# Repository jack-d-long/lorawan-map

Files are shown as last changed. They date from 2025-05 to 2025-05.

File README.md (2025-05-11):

# LoRaWAN Tracker
*Modified Spring 2025 by Jack Long, Charlie Hart, Aleira Sanchez, Chloe Teig for MAE 4220: IoT, Cornell University*

*Originally by Alex Coy, ECE 4950 TA for Spring 2021*

A one‑stop repository for everything you need to build, deploy, and visualize data from our GPS LoRaWAN tracker:

- **Map App** (`map‑app/`)  
  A lightweight web application for ingesting the raw `.txt` logs off the tracker’s onboard SD card and rendering an interactive, real‑time map of your device’s journey.

- **Tracker Hardware** (`tracker‑hardware/`)  
  - **Shell** (`tracker‑hardware/shell_CAD/`)  
    Fully parametric OpenSCAD/STEP files and detailed drawings for 3D‑printing or CNC fabrication of the tracker enclosure.  
  - **Firmware** (`tracker‑hardware/firmware/`)  
    PlatformIO‑compatible C/C++ code for the microcontroller: SD‑card logger, GNSS reader, LoRaWAN uplink, and low‑power sleep modes with GUI.
  - **Purple Board** (`tracker‑hardware/firmware/`)
    KiCAD-compatible files for manufacture and assembly of the EERL 'Purple Board' PCB by Alex Coy, current as of May 2025. 
---

## Repository Structure

```plaintext
lorawan-map/
├── map-app/                   # Web application
│   ├── connectivity_app.py    # Streamlit entrypoint
│   ├── requirements.txt       # Python dependencies
│   ├── templates/             # HTML templates
│
├── tracker-hardware/          
│   ├── shell_CAD/                   # OpenSCAD & STEP enclosure files
│   ├── purple_board/                # EERL purple board docs
│   └── firmware/              
│       ├── feather_sd_sam-m8q-/     # C/C++ source with all proprietary headers
│
├── .gitignore                 
└── README.md                  # ← you are here

```

## The LoRaWAN Tracker 

###  Features

- **Scan and Record LoRaWAN connectivity** Either store data onboard the SD or pull from The Things Network for custom database integration
- **Battery‑aware operation**: real‑time voltage monitoring and on‑screen battery bar  
- **Dual scan modes** (“Drive” vs “Walk”) with adaptive transmit intervals (15 s vs 60 s)  
- **Non‑blocking UI controls**: five‑button D‑pad menu navigation with hardware‑debounced inputs  
- **Persistent storage**: 32 kB FRAM for network session state (optional) + SD card for full JSON logging  
- **Plug‑and‑play web front‑end**: drag‑and‑drop `.txt` logs to visualize GPS tracks, timestamps and sensor graphs  

---

###  Hardware Requirements

- **Microcontroller**: Adafruit Feather M0 LoRa ([RFM95, 915 MHz](https://www.adafruit.com/product/3178))  
- **"Purple Board"**: EERL PCB (source included)
- **Display**: [SH1106 128×64 I²C OLED](https://www.aliexpress.us/item/3256806846801359.html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)
- **GPS**: u‑blox SAM‑M8Q module ([Sparkfun breakout](https://www.sparkfun.com/sparkfun-gps-breakout-chip-antenna-sam-m8q-qwiic.html))  
- **Storage**: [MicroSD card breakout](https://www.amazon.com/UMLIFE-Interface-Conversion-Compatible-Raspberry/dp/B0989SM146) with Micro SD (>8GB) + MCCI Catena cFram32k FRAM (optional)
- **Controls**: [PCA9554 I²C D‑Pad](https://www.sparkfun.com/sparkfun-qwiic-directional-pad.html) + [12mm latching pushbutton](https://www.amazon.com/Gebildet-Latcting-Lockable-Trumpet-Doorbell/dp/B07YDCJFZJ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)
- **Power**: 3.7 V 1S/3C LiPo battery (800-1000 mAh)   
- **Enclosure**: 3D‑printed shell (source included)  

---

### Software Requirements

- **Arduino IDE**   
- Libraries:  
  - `Arduino_LoRaWAN_ttn` + `lmic`  
  - `Adafruit GFX` & `Adafruit SH110X`  
  - `SparkFun u‑blox GNSS` & `TinyGPS`  
  - `SparkFun I2C Expander`  
  - `MCCI Catena FrAM`  
- **Node.js** (v14+) & **npm** for the web app  
- Web dependencies: `express`, `react`, `leaflet`, `chart.js`

---

## Usage

**1. Clone the repo**
```
git clone https://github.com/jack-d-long/lorawan-map.git
cd lorawan-map
```

**2. Build the tracker**
- Purchase components, print shell, assemble.
  - Printed with PLA at 0.2 mm layer height, tree supports
- Flash firmware with Arduino IDE

**3. Use the tracker**
- Collect data on LoRaWAN connectivity in your local area

**4. Set up the map app**
- Install dependencies

```
pip install --upgrade pip
pip install \
  streamlit \
  pandas \
  pydeck \
  jsonschema  # optional: validate JSON if you extend
```

**5. Read your stored data card with the map app**
- Read your tracker's SD storage with your computer
- Run the app

```
streamlit run connectivity_app.py
```
- Drag and drop the `.txt` file from the SD into the app
- Read your map!

**6. Read your data on the cloud via TTN**

- Set up TTN by following Labs 3, 4, 5, and 6 of [this tutorial](https://pages.github.coecis.cornell.edu/LPWAN-Training/training-labs/lab3), or equivalent
- Pipe your data via MQTT to the database of your choice for live retrieval

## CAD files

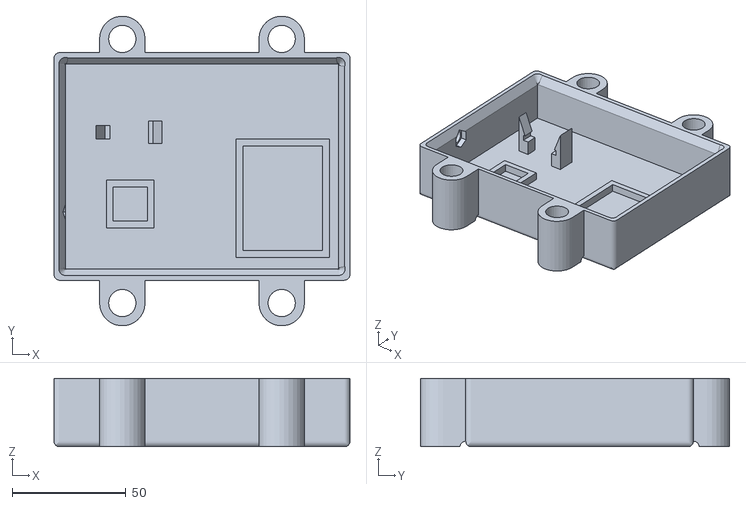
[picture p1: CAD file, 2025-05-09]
tracker-hardware/shell_CAD/car_mount/top_encl_sam_m8q.stl
130.0 x 135.9 x 30.0

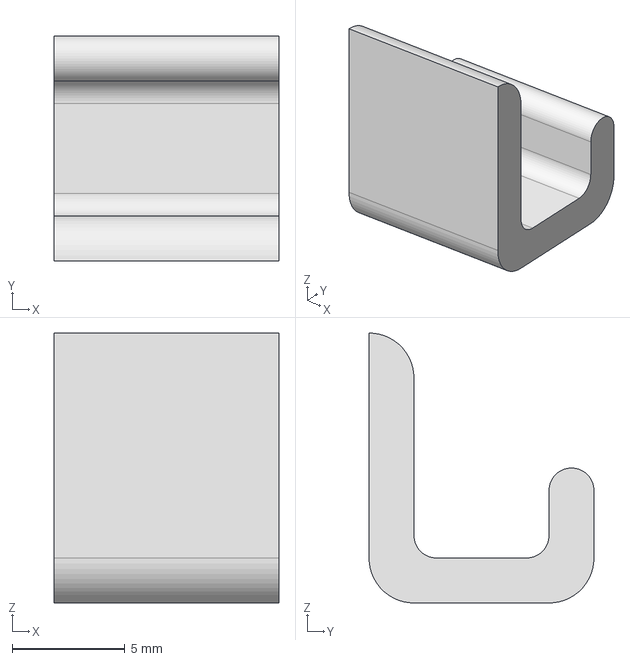
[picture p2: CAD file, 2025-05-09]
tracker-hardware/shell_CAD/handheld/V3/step/Car Window Mount.stp
10.0 x 10.0 x 12.0 mm

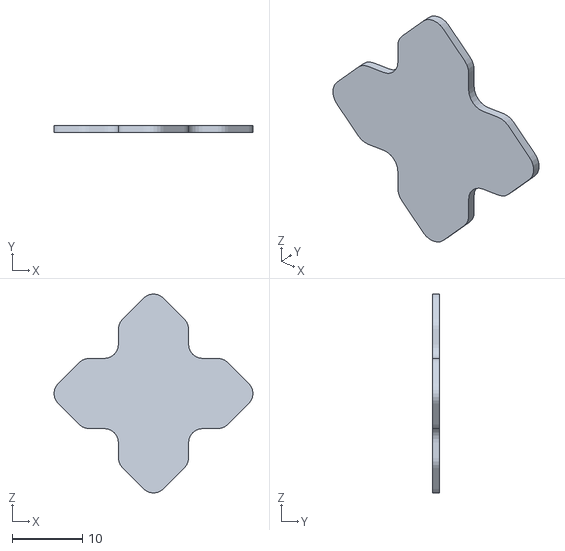
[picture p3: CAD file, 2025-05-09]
tracker-hardware/shell_CAD/handheld/V3/stl/D-pad cover new.stl
28.3 x 1.00 x 28.3

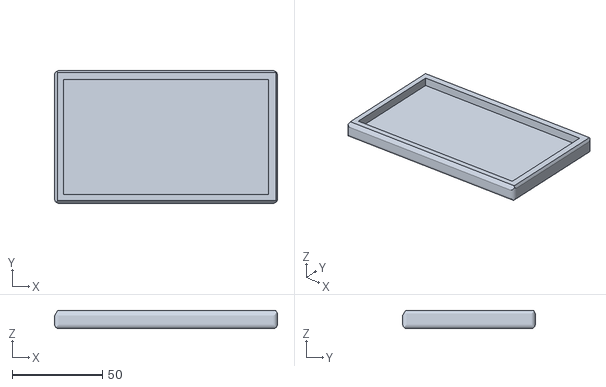
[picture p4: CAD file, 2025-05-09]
tracker-hardware/shell_CAD/car_mount/bottom_encl_sam_m8q_pcb.stl
123.5 x 73.5 x 10.0

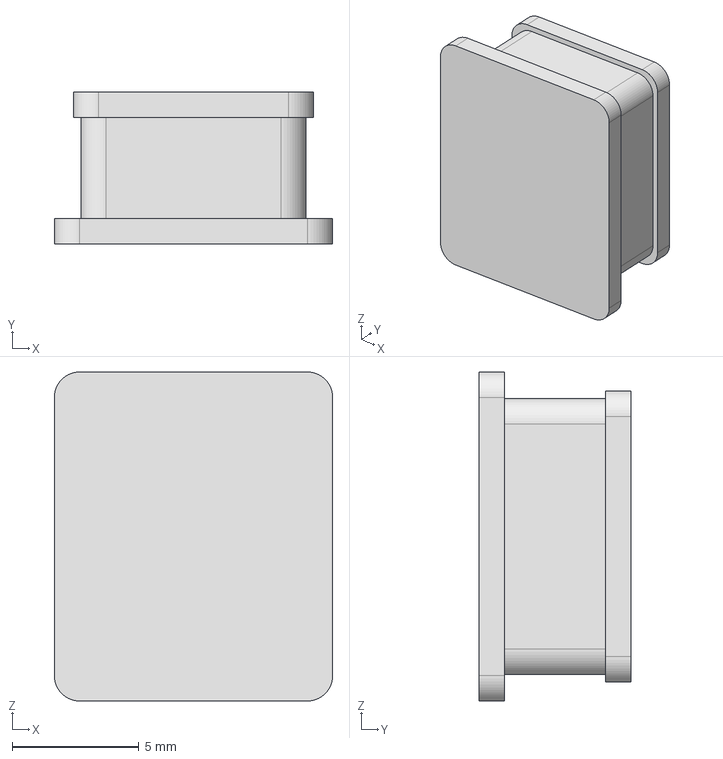
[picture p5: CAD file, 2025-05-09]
tracker-hardware/shell_CAD/handheld/V3/step/USB Cover.stp
11.0 x 6.00 x 13.0 mm

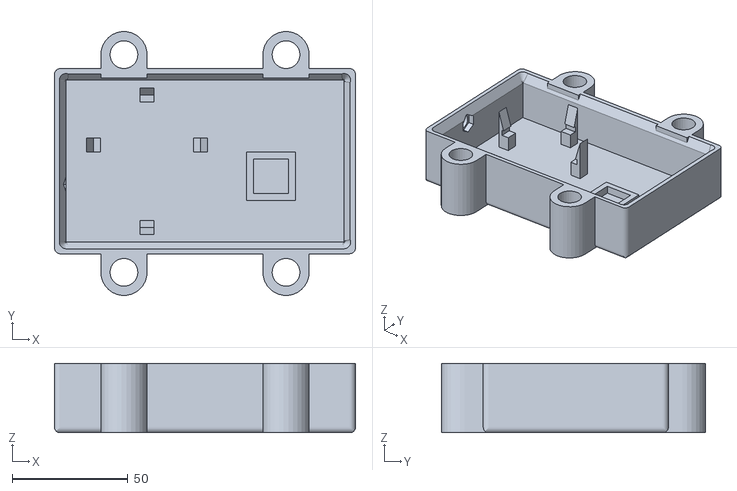
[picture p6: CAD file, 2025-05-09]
tracker-hardware/shell_CAD/car_mount/top_encl_sam_m8q_pcb.stl
130.0 x 113.9 x 30.0

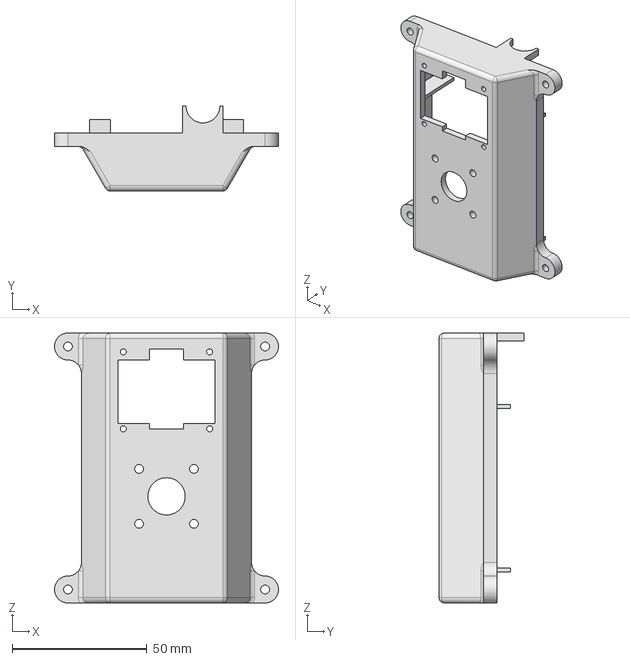
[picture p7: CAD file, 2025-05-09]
tracker-hardware/shell_CAD/handheld/V3/step/Front.stp
83.0 x 31.5 x 100.0 mm

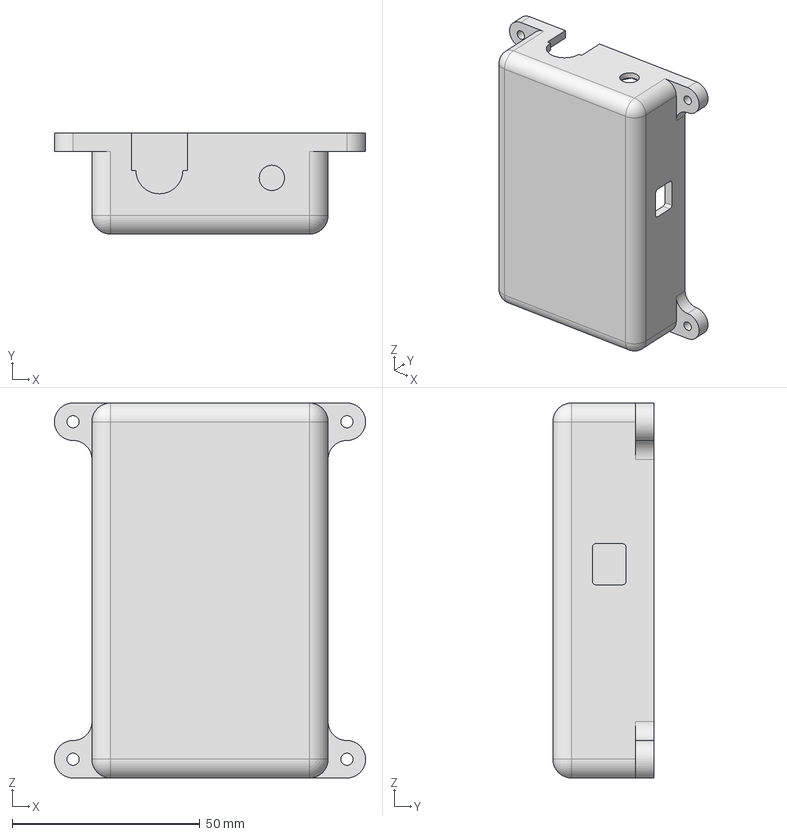
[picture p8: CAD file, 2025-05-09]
tracker-hardware/shell_CAD/handheld/V3/step/Back_new.stp
83.0 x 27.0 x 100.0 mm

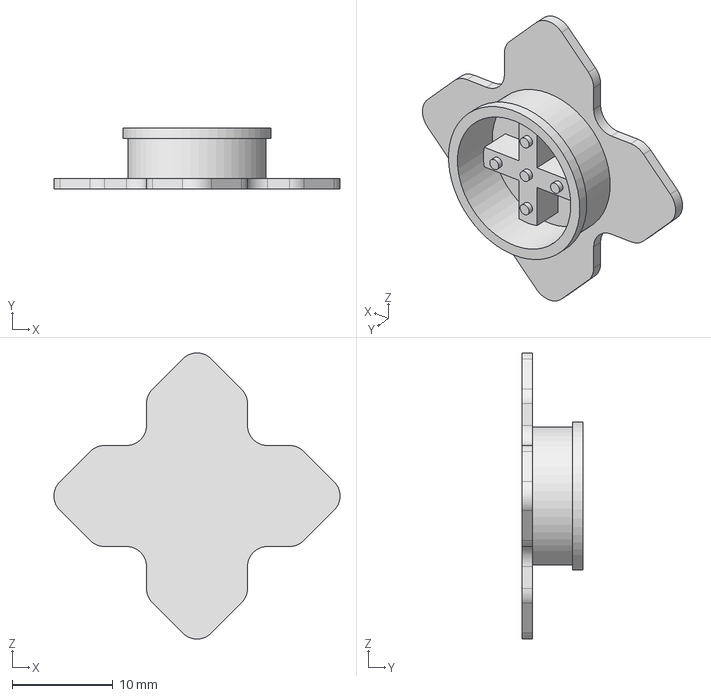
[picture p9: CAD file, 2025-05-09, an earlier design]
tracker-hardware/shell_CAD/handheld/V1/step/D-pad cover.stp
28.3 x 6.00 x 28.3 mm

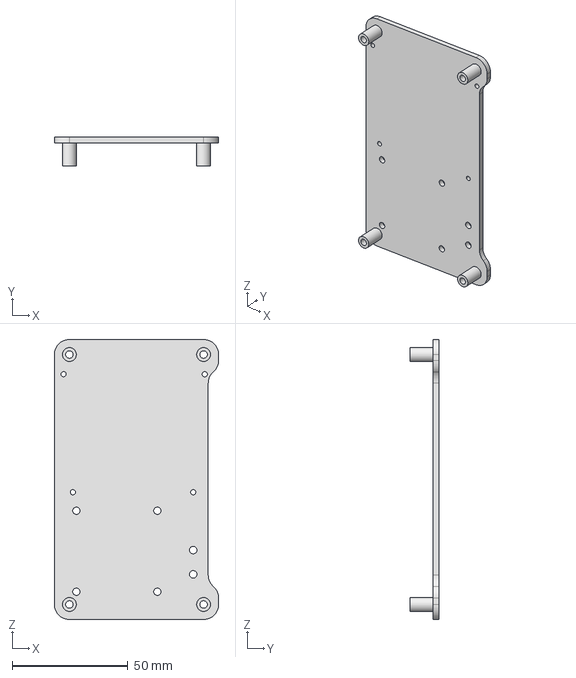
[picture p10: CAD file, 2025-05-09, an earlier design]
tracker-hardware/shell_CAD/handheld/V1/step/New_Plate.stp
71.0 x 12.5 x 121.0 mm

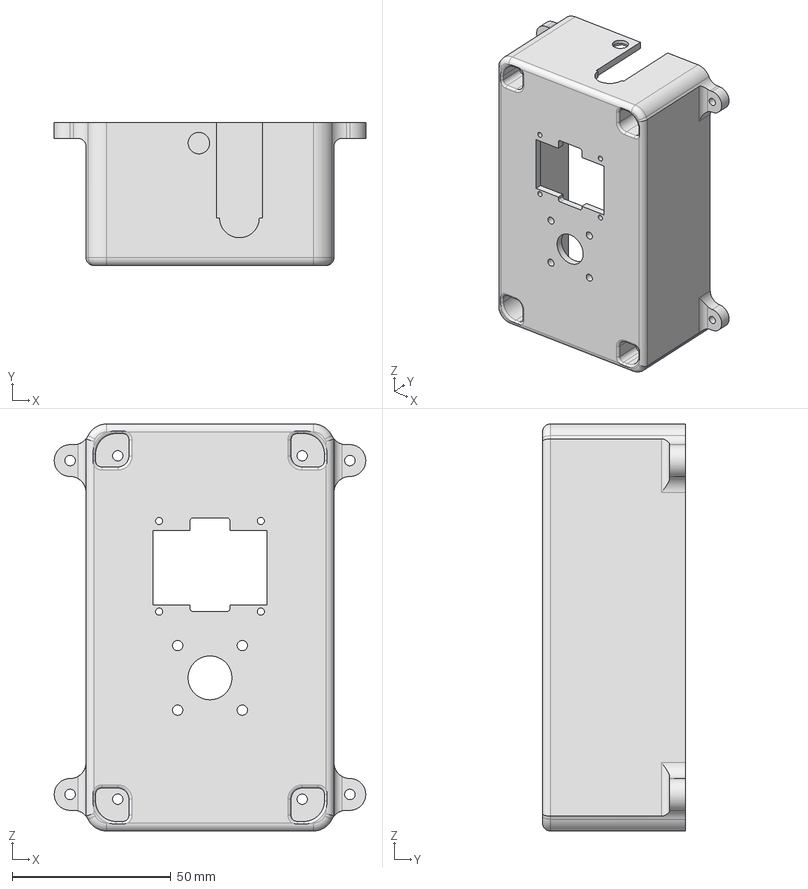
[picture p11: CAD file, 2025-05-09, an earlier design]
tracker-hardware/shell_CAD/handheld/V1/step/Bottom Case.stp
98.0 x 45.0 x 128.0 mm

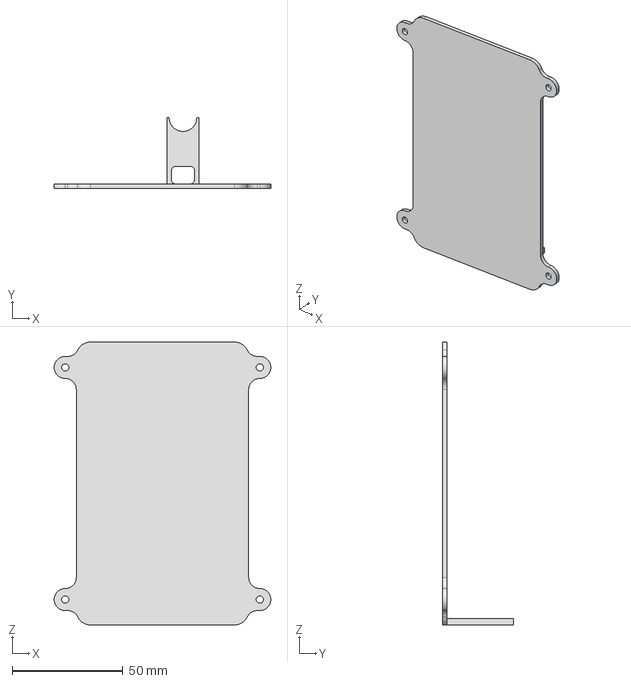
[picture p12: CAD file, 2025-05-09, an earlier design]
tracker-hardware/shell_CAD/handheld/V1/step/Top_Part1.stp
98.0 x 32.0 x 128.0 mm

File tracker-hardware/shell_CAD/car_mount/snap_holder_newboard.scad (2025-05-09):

//snap_holder_newboard();
//cube([50, 6, 3], center=true);
//translate([0,0,0])
//cube([6, 23, 3], center=true);

snap_arm(stand_height=8.5,shrink_factor=0);

module snap_arm(stand_height=10, lip_height=3, length=6, shrink_factor=0){
        cube([length-shrink_factor,6-shrink_factor,stand_height]);
        cube([length-shrink_factor,1,stand_height+lip_height+2]);
        translate([0,0,stand_height+lip_height])
        rotate([90,0,90])
        linear_extrude(length-shrink_factor)
        polygon([[0,0], [0,10], [3,0]]);
    }

module snap_holder_newboard(){
    
    
    
    translate([-3,-59.25/2-2,-1.5])
    snap_arm();
    translate([3,+59.25/2+2,-1.5])
    rotate([0,0,180])
    snap_arm();
    
    translate([56.25/2+2,-3+7,-1.5])
    rotate([0,0,90])
    snap_arm();
    translate([-56.25/2-2,3+7,-1.5])
    rotate([0,0,270])
    snap_arm();
    /*
    translate([107/2+3,-3,-1.5])
    rotate([0,0,90])
    snap_arm();
    
    translate([-107/2-3,3,-1.5])
    rotate([0,0,-90])
    snap_arm();
    */
}

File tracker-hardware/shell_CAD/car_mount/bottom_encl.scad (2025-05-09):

bottom_encl();

module bottom_encl(){
    g_w = 125;
    g_l = 95;
    
    translate([-g_w/2, -g_l/2, 0])
    difference(){
        union(){
        cube([g_w, g_l, 10]);


        }
        union(){
        translate([5, 5, 5])
            cube([g_w-10, g_l-10, 60]);
        }
        
        translate([g_w, g_l, -0.1])
            rotate([0,0,180])
            fillet(60,5);
            
            translate([g_w, 0, -0.1])
            rotate([0,0,90])
            fillet(60,5);
            
       translate([0, g_l, -0.1])
            rotate([0,0,270])
            fillet(60,5);
            
            translate([0, 0, -0.1])
            rotate([0,0,0])
            fillet(60,5);
        
        translate([0, g_l, -0.1])
            rotate([0,90,0])
            rotate([0,0,180])
            fillet(g_w,5);
            
        translate([0, 0, -0.1])
            rotate([0,90,0])
            rotate([0,0,90])
            fillet(g_w,5);
            
        translate([0, g_w, -0.1])
            rotate([90,0,0])
            rotate([0,0,0])
            fillet(g_w,5);
            
        translate([g_w, 0, -0.1])
            rotate([90,0,0])
            rotate([0,0,90])
            fillet(g_w,5);
            
        translate([g_w, 0, -0.1])
            rotate([-90,0,0])
            rotate([0,0,180])
            fillet(g_w,5);
            
        translate([0,1,9])
        rotate([60,0,0])
        translate([0,-22,0])
        cube([130,30,3]);
        
        translate([0,89,17])
        rotate([-60,0,0])
        translate([0,5,0])
        cube([130,30,3]);
        
        translate([0,0,7])
        rotate([0,-60,0])
        cube([30,105,3]);
        
        translate([119,0,17])
        rotate([0,60,0])
        cube([30,100,3]);
    }
    
    translate([-17,-20,5])
    union(){
        cube([4,10,10]);
        translate([68+4,0,0])
        cube([4,10,10]);
        translate([30,-24+56,0])
        cube([10,4,10]);
    }
}

module fillet(h, d){
    difference(){
        cylinder(h=h, d=d, $fn=30);
        union(){
            translate([d/2, d/2, -0.1])
            cylinder(h=h+0.2, d=d, $fn=30);
        }
    }
}

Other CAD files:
tracker-hardware/shell_CAD/car_mount/bottom_encl_sam_m8q_pcb.scad
tracker-hardware/shell_CAD/car_mount/snap_holder.scad
tracker-hardware/shell_CAD/car_mount/snap_holder_feather.scad
tracker-hardware/shell_CAD/car_mount/top_encl.scad
tracker-hardware/shell_CAD/car_mount/top_encl_sam_m8q.scad
tracker-hardware/shell_CAD/car_mount/top_encl_sam_m8q_pcb.scad
tracker-hardware/shell_CAD/handheld/V1/stl/Bottom Case.stl
tracker-hardware/shell_CAD/handheld/V1/stl/D-pad cover.stl
tracker-hardware/shell_CAD/handheld/V1/stl/New_Plate.stl
tracker-hardware/shell_CAD/handheld/V1/stl/Top_Part1.stl
tracker-hardware/shell_CAD/handheld/V3/stl/Back_new.stl
tracker-hardware/shell_CAD/handheld/V3/stl/Car Window Mount.stl
tracker-hardware/shell_CAD/handheld/V3/stl/Front.stl
tracker-hardware/shell_CAD/handheld/V3/stl/USB Cover.stl

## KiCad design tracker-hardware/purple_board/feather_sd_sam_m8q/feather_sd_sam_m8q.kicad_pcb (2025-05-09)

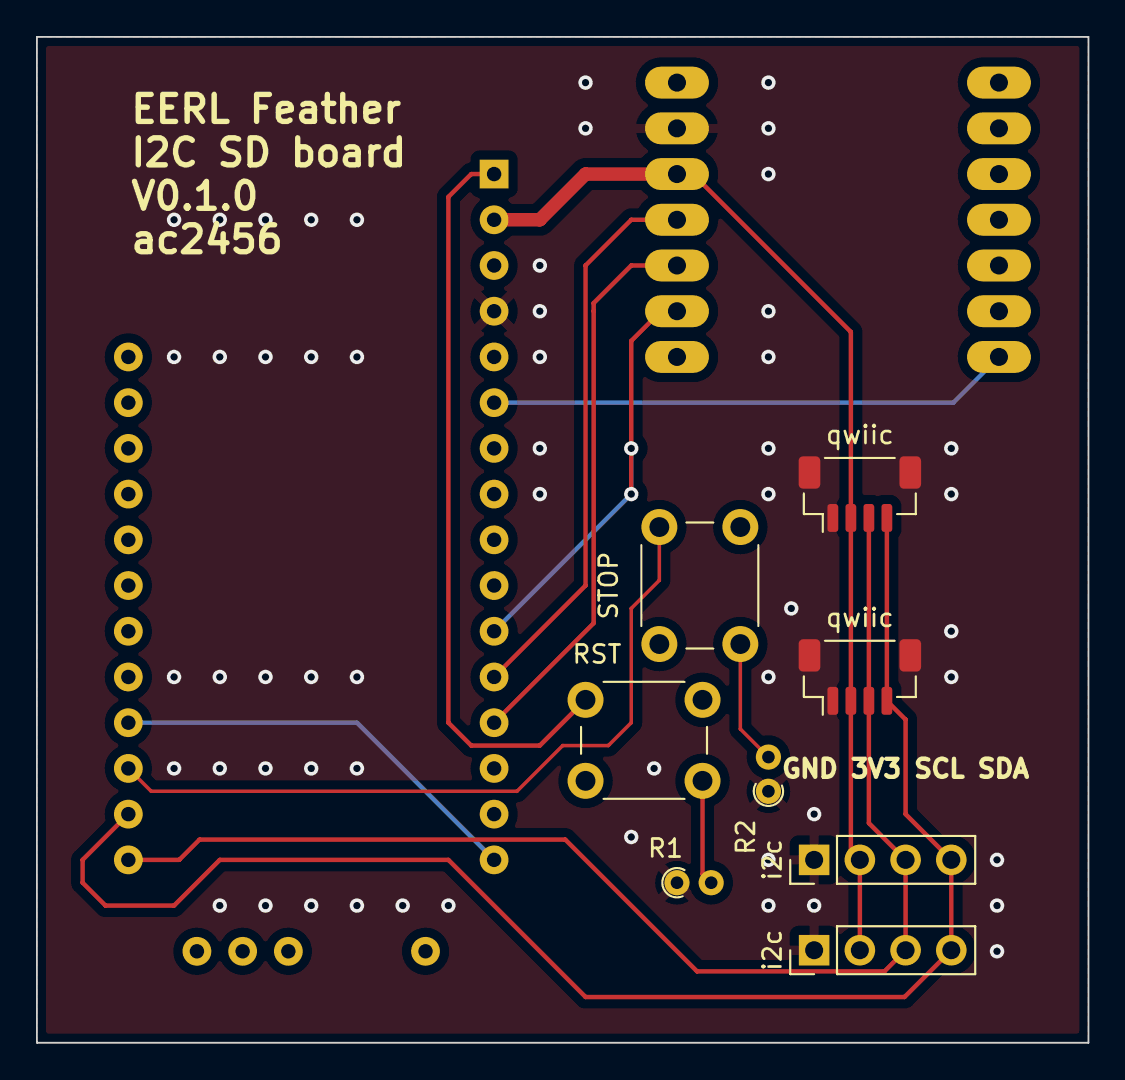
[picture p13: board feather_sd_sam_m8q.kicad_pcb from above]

Board: 2 copper layers, 58.4 x 55.9 mm, 9 parts (1 on the bottom side), 7 nets.

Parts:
A1: Adafruit_Feather_M0_RFM9x_LoRa_Radio; Adafruit_Feather_M0_RFM
R1, R2: R_Axial_DIN0204_L3.6mm_D1.6mm_P1.90mm_Vertical
RST: SW_PUSH_6mm
STOP: SW_PUSH_6mm
i2c, i2c#2: PinHeader_1x04_P2.54mm_Vertical
qwiic: JST_SH_BM04B-SRSS-TB_1x04-1MP_P1.00mm_Vertical
qwiic#2: JST_SH_BM04B-SRSS-TB_1x04-1MP_P1.00mm_Vertical

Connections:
/SCL: A1.18 (SCL/D21), i2c.4, i2c#2.4, qwiic.4, qwiic#2.4
/SDA: A1.17 (SDA/D20), i2c.3, i2c#2.3, qwiic.3, qwiic#2.3
/VDD3v: A1.2 (3V3), i2c.2, i2c#2.2, qwiic.2, qwiic#2.2
/VSS: A1.4 (GND), R1.1, R2.1, i2c.1, i2c#2.1, qwiic.1, qwiic.MP, qwiic#2.1, qwiic#2.MP
/jp6_1: A1.16 (DIO1), A1.20 (D6)
RST: A1.1 (~RESET), RST.1
stop_button: A1.19 (D5), STOP.1

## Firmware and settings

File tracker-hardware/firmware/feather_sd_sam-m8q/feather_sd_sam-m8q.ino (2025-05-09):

/*

Module:  simple_feather.ino

Function:
        Example app matching the documentation in the project
	README.md, showing how to configure a board explicitly

Copyright notice and License:
        See LICENSE file accompanying this project.

Author:
        Terry Moore, MCCI Corporation	November 2018
        Alex Coy, ECE 4950 TA for Spring 2021
	Jack Long, MAE 4220 Student Spring 2025

Notes:
	This app is not complete -- it only presents skeleton
	code for the methods you must provide in order to
	use this library. However, it compiles!

*/

#ifdef COMPILE_REGRESSION_TEST
#define FILLMEIN 0
#else
#define FILLMEIN (#Don't edit this stuff. Fill in the appropriate FILLMEIN values.)
#warning "You must fill in your keys with the right values from the TTN control panel"
#endif

#include <Arduino_LoRaWAN_ttn.h>
#include <lmic.h>
#include <hal/hal.h>
#include "keys.h"
#include "Catena_Fram32k.h"
#include "TTN_mapper_packager.h"
#include <TinyGPS.h>
#include <SparkFun_u-blox_GNSS_Arduino_Library.h>
#include "Wire.h"
#include "filemgmt.h"

#include <Adafruit_GFX.h>
#include <Adafruit_SH110X.h>
#include <SparkFun_I2C_Expander_Arduino_Library.h> // Click here to get the library: http://librarymanager/All#SparkFun_I2C_Expander_Arduino_Library


#include <SD.h>
File g_file;

// OLED Setup
#define SCREEN_WIDTH 128
#define SCREEN_HEIGHT 64
Adafruit_SH1106G display(SCREEN_WIDTH, SCREEN_HEIGHT, &Wire, -1);

// D-Pad setup
SFE_PCA95XX io; // Defaults to the PCA9554 at I2C address 0x20


#define GPS_TIME 5000

uint64_t lastTime = 0;
uint32_t bufferLength = 8;
static uint8_t messageBuffer[8] = { 0, 1, 2, 3, 4, 5, 6, 7 };
static eerl::ttnmapbuf_t buf;
bool can_use_gps = true;

TinyGPS gps;



SFE_UBLOX_GNSS myGNSS;
eerl::TtnPackager packer;
// constexpr uint64_t TX_INTERVAL = 15000;
static bool sending_packet = false;
bool loraConnected;
int menu_idx = 0; //OLED
bool press_up;
bool press_down;
bool press_left;
bool press_right;
bool press_sel;
uint64_t tx_interval = 15000;


// state vars
bool state_menu;
bool state_walkscan;
bool state_drivescan;
bool screen_on;




// D-pad vars
const int buttonUp = 0;
const int buttonDown = 1;
const int buttonRight = 2;
const int buttonLeft = 3;
const int buttonCenter = 4;
const int ledBlue = 5;
const int ledGreen = 6;
const int ledRed = 7;
 int menuIndex = 0;
const int kDebounceDelay = 200; //ms

static const unsigned char signal_icon[] PROGMEM = {
  0b00000000,  // Row 0 (top)
  0b00000000,  // Row 1
  0b00000001,  // Row 2 – tallest bar only
  0b00000001,  // Row 3 – tallest bar
  0b00000101,  // Row 4 – bars 3 and 4
  0b00000101,  // Row 5 – bars 3 and 4
  0b00010101,  // Row 6 – bars 2, 3, and 4
  0b01010101   // Row 7 (bottom) – all 4 bars
};

static const unsigned char no_signal_icon[] PROGMEM = {
  0b00000000,  // Row 0 (top)
  0b00000000,  // Row 1
  0b00000000,  // Row 2
  0b00000000,  // Row 3
  0b00000000,  // Row 4
  0b00000101,  // Row 5 – bars 3 and 4
  0b00010101,  // Row 6 – bars 2, 3, and 4
  0b00010101   // Row 7 (bottom) – all 4 bars
};

static const unsigned char gps_icon[] PROGMEM = {
  0b00011000,
  0b00111100,
  0b01111110,
  0b11111111,
  0b11111111,
  0b01111110,
  0b00111100,
  0b00011000
};


#ifdef __cplusplus
extern "C" {
#endif

  void myStatusCallback(void *data, bool success) {
    Serial.println("Enter status callback");
    if (success) {
      Serial.println("Succeeded!");
      loraConnected = true;  //added for OLED
    } else {
      Serial.println("Failed!");
      loraConnected = false;  //added for OLED
    }
    can_use_gps = true;
    digitalWrite(LED_BUILTIN, 0);
    sending_packet = false;
  }

  void dateTime(uint16_t *date, uint16_t *time) {
    if (myGNSS.getDateValid()) {
      // return date using FAT_DATE macro to format fields
      *date = FAT_DATE(myGNSS.getYear(), myGNSS.getMonth(), myGNSS.getDay());
    }
    if (myGNSS.getTimeValid()) {
      *time = FAT_TIME(myGNSS.getHour(), myGNSS.getMinute(), myGNSS.getSecond());
    }
  }

#ifdef __cplusplus
}
#endif

class cMyLoRaWAN : public Arduino_LoRaWAN_ttn {
  bool M_FRAM_GOOD = false;
public:
  McciCatena::cFram32k theFram;
  cMyLoRaWAN(){};

  bool begin(const lmic_pinmap &map) {
    M_FRAM_GOOD = true;

    if (!theFram.begin()) {
      Serial.println("Fram begin fail");
      //return false;
    }

    if (!theFram.begin() || !theFram.initialize()) {
      Serial.println("Fram init fail");
      M_FRAM_GOOD = false;
    }


    if (!Arduino_LoRaWAN_ttn::begin(map))
      return false;

    return true;
  }

protected:
  // you'll need to provide implementations for each of the following.
  virtual bool GetOtaaProvisioningInfo(Arduino_LoRaWAN::OtaaProvisioningInfo *) override;
  virtual void NetSaveSessionInfo(const SessionInfo &Info, const uint8_t *pExtraInfo, size_t nExtraInfo) override;
  virtual void NetSaveSessionState(const SessionState &State);
  virtual bool NetGetSessionState(SessionState &State);
  virtual bool GetAbpProvisioningInfo(
    AbpProvisioningInfo *pProvisioningInfo);
};

// set up the data structures.
cMyLoRaWAN myLoRaWAN{};

// The pinmap. This form is convenient if the LMIC library
// doesn't support your board and you don't want to add the
// configuration to the library (perhaps you're just testing).
// This pinmap matches the FeatherM0 LoRa. See the arduino-lmic
// docs for more info on how to set this up.
const cMyLoRaWAN::lmic_pinmap myPinMap = {
  .nss = 8,
  .rxtx = cMyLoRaWAN::lmic_pinmap::LMIC_UNUSED_PIN,
  .rst = 4,
  .dio = { 3, 6, cMyLoRaWAN::lmic_pinmap::LMIC_UNUSED_PIN },
  .rxtx_rx_active = 0,
  .rssi_cal = 0,
  .spi_freq = 8000000,
};

void send_packet() {
  // Prepare upstream data transmission at the next possible time.
  //LMIC_setTxData2(1, (u1_t *)&buf, sizeof(eerl::ttnmapbuf_t)-1, 0);
  myLoRaWAN.SendBuffer((u1_t *)&buf, sizeof(eerl::ttnmapbuf_t), myStatusCallback, NULL, false, 1);
  Serial.println(F("Packet queued"));
  can_use_gps = false;
  sending_packet = true;
  lastTime = millis();
  digitalWrite(LED_BUILTIN, 1);
}

// void show() {
//   display.display();
//   delay(2000);
//   display.fillScreen(SH110X_WHITE);
// }

void setup() {
  // simply pass the pinmap to the begin() method.
  Serial.begin(115200);
  Serial1.begin(9600);

  pinMode(LED_BUILTIN, OUTPUT);
  digitalWrite(LED_BUILTIN, 1);
  {
    uint64_t lt = millis();
    while (!Serial && millis() - lt < 5000)
      ;
  }
  Serial.println("Serial begin");

  pinMode(A1, OUTPUT);
  digitalWrite(A1, 1);

  pinMode(8, OUTPUT);
  digitalWrite(8, 1);

  // OLED init
  if (!display.begin(0x3C, true)) {
    Serial.println(F("OLED not found"));
    while (1)
      ;
  }
  display.setTextSize(1);                // normal 1× text
  display.setTextColor(SH110X_WHITE);

  state_menu    = true;   // start in the menu
  screen_on     = true;   // allow the screen to turn on
  state_walkscan  = false;
  state_drivescan = false;


  display.clearDisplay();
  display.display();
  Serial.println("Startup Screen");

  // STARTUP SCREEN
  display.setTextSize(2);     
  display.setCursor(16, 10); // for a centered X value: X = (124 - (characters * 8))/2 
  display.println(" LoRaWan");
  display.setCursor(52, 20);
  //display.println(*CHANGE THIS*);
  display.setCursor(28, 35);
  display.println("Tracker");

  display.display();
  display.setTextSize(1);     
  

  // Init lorawan
  if (!myLoRaWAN.begin(myPinMap)) {
    Serial.println("LoRaWAN begin fail");
    while (1)
      ;
  }
  // Init GPS
  delay(3000);
  if (myGNSS.begin() == false) {
    Serial.println(F("u-blox GNSS not detected at default I2C address. Please check wiring. Freezing."));
    while (1)
      ;
  }
  can_use_gps = true;

   // Initialize the PCA9554, default address = 0x20
  if (io.begin() == false) //Device Address, Number of GPIO
  {
    Serial.println("PCA9554 not detected. Please check wiring. Freezing...");
    while (1)
      ;
  }
  io.pinMode(buttonUp, INPUT);
  io.pinMode(buttonDown, INPUT);
  io.pinMode(buttonLeft, INPUT);
  io.pinMode(buttonRight, INPUT);
  io.pinMode(buttonCenter, INPUT);
  io.pinMode(ledRed, OUTPUT);
  io.pinMode(ledGreen, OUTPUT);
  io.pinMode(ledBlue, OUTPUT);






  startSD();
  setGlobalFile();
  if (g_file) {
    Serial.println("Successful SD Reset");
    g_file.println("{\"Successful Reset\":true}");
    //g_file.println("{\"DEVEUI\":");
    g_file.close();
  }

  lastTime = millis();

  if (myLoRaWAN.IsProvisioned())
    Serial.println("Provisioned for something");
  else
    Serial.println("Not provisioned.");
  //LMIC.datarate = 1;
  //myLoRaWAN.SendBuffer(messageBuffer, bufferLength, myStatusCallback, NULL, false, 1);
  //pinMode(LED_BUILTIN, OUTPUT);
  digitalWrite(LED_BUILTIN, 0);

  myGNSS.setI2COutput(COM_TYPE_UBX);                  //Set the I2C port to output both NMEA and UBX messages
  myGNSS.saveConfigSelective(VAL_CFG_SUBSEC_IOPORT);  //Save (only) the communications port settings to flash and BBR
  //myGNSS.setNMEAOutputPort(Serial);
  send_packet();
}

void check_button_presses() {
  // clear the pressed flags each time
  press_up = press_down = press_left = press_right = press_sel = 0;

  // keep track of last time any button was accepted
  static unsigned long lastDebounceTime = 0;

  // figure out which (if any) button is currently down
  int curr = -1;
  if (io.digitalRead(buttonUp)    == LOW) curr = buttonUp;
  else if (io.digitalRead(buttonDown)  == LOW) curr = buttonDown;
  else if (io.digitalRead(buttonLeft)  == LOW) curr = buttonLeft;
  else if (io.digitalRead(buttonRight) == LOW) curr = buttonRight;
  else if (io.digitalRead(buttonCenter)== LOW) curr = buttonCenter;

  unsigned long now = millis();

  // only register a new press if it’s been > kDebounceDelay since the last one
  if (curr != -1 && (now - lastDebounceTime > kDebounceDelay)) {
    lastDebounceTime = now;  // reset lock‑out timer

    switch (curr) {
      case buttonUp:
        press_up = 1;
        Serial.println("Up");
        break;
      case buttonDown:
        press_down = 1;
        Serial.println("Down");
        break;
      case buttonLeft:
        press_left = 1;
        Serial.println("Left");
        break;
      case buttonRight:
        press_right = 1;
        Serial.println("Right");
        break;
      case buttonCenter:
        press_sel = 1;
        Serial.println("Center");
        break;
    }
  }
}


void drawMenu(){
  display.clearDisplay();

  display.setCursor(40, 0);
  display.println("Menu");
  display.drawLine(0, 10, 128, 10, SH110X_WHITE);

  // Menu options
  if (menuIndex == 0) {
    display.setCursor(0, 20);
    display.print("> ");
    display.print("Drive Scan");
    
    display.setCursor(10, 30);
    display.print("Walk Scan");

  } else if (menuIndex == 1) {
    display.setCursor(10, 20);
    display.print("Drive Scan");

    display.setCursor(0, 30);
    display.print("> ");
    display.print("Walk Scan");
  }

  display.display();
}
float readBatteryVoltage() {
  int raw = analogRead(A7);              // 1023
  float vOut = (raw * 3.3f) / 1023.0f;            // divided voltage at pin
  return vOut * 2.0f;                            // compensate for 2:1 divider
}
// map voltage→0–100%, clamp at extremes
uint8_t voltageToPercent(float v) {
  float pct = (v - 3.0) / (4.18 - 3.0) * 100.0f;
  if (pct < 0)   pct = 0;
  if (pct > 100) pct = 100;
  return static_cast<uint8_t>(pct + 0.5f);
}

void loop() {
  myLoRaWAN.loop();

  static unsigned long lt_gps = millis();

  bool newData = false;
  unsigned long chars;
  unsigned short sentences, failed;

  // Check for button presses 

  check_button_presses();

  if (state_menu){
    //MENU SCREEN - need to connect the D-pad
    drawMenu();                         // ← redraw every pass
  // Serial.println(" drew menu");
  if (press_up)   menuIndex = (menuIndex - 1 + 2) % 2;
  if (press_down) menuIndex = (menuIndex + 1) % 2;
  if (press_sel)  {  // state transition from menu to scan
    if (menu_idx == 0) {
        state_menu = 0;
        state_drivescan = 1;
        display.clearDisplay();
        display.display();


      } else if (menu_idx == 1) {
        state_menu = 0; 
        state_walkscan = 1;
        display.clearDisplay();
        display.display();
      }
   }
    
  }

  if (state_walkscan || state_drivescan){
    if (state_walkscan){
      tx_interval = 60000;
    }else{
      tx_interval = 15000;
    }

  // turn screen off if down button pressed, or go back to menu

    if (press_down){
      screen_on = 0;
    }
    if (press_up){
      screen_on = 1;
    }

    if (press_left){
      state_walkscan = 0;
      state_drivescan = 0;
      state_menu = 1;
    }
     


    if (millis() - lt_gps > GPS_TIME) {
      lt_gps = millis();
      Serial.println("Look for new GPS");

      if (myGNSS.getGnssFixOk()) {
        digitalWrite(LED_BUILTIN, 1);
        delay(100);
        digitalWrite(LED_BUILTIN, 0);
        float flat, flon, falt;
        unsigned long age;

        flat = (float)myGNSS.getLatitude() / 10000000;
        Serial.println("Lat: ");
        Serial.println(flat);


        flon = (float)myGNSS.getLongitude() / 10000000;
        Serial.println("Long: ");
        Serial.println(flon);
        falt = (float)myGNSS.getAltitude() / 1000;  // in meters
        Serial.println("Alt: ");
        Serial.println(falt);


        packer.setLat(flat);
        packer.setLon(flon);
        packer.setAlt(falt);
        packer.setHdop(myGNSS.getPDOP());
        packer.setStamp(myGNSS.getUnixEpoch());

        packer.packBuffer(&buf);
        uint16_t vBat = analogRead(A7);
        buf.i_bat = vBat;

        setGlobalFile();
        if (g_file) {
          g_file.print("{");
          g_file.print("\"latitude\":");
          g_file.print(buf.f_lat, 14);
          g_file.print(",");
          g_file.print("\"longitude\":");
          g_file.print(buf.f_lon, 14);
          g_file.print(",");
          g_file.print("\"altitude\":");
          g_file.print(buf.alt, 14);
          g_file.print(",");
          g_file.print("\"pdop\":");
          g_file.print(buf.hdop);

          if (myGNSS.getDateValid()) {
            g_file.print(",");
            g_file.print("\"year\":");
            g_file.print(myGNSS.getYear());
            g_file.print(",");
            g_file.print("\"month\":");
            g_file.print(myGNSS.getMonth());
            g_file.print(",");
            g_file.print("\"day\":");
            g_file.print(myGNSS.getDay());
          }
          if (myGNSS.getTimeValid()) {
            g_file.print(",");
            g_file.print("\"hour\":");
            g_file.print(myGNSS.getHour());
            g_file.print(",");
            g_file.print("\"minute\":");
            g_file.print(myGNSS.getMinute());
            g_file.print(",");
            g_file.print("\"second\":");
            g_file.print(myGNSS.getSecond());
          }
        }



        if (millis() - lastTime > tx_interval) {

          if (g_file) {
            g_file.print(",");
            g_file.print("\"LoRaWANSend\":");
            g_file.print(loraConnected);
            g_file.print(",");
            g_file.print("\"txpow\":");
            g_file.print(LMIC.radio_txpow);
            g_file.print("}\n");
            g_file.close();
            Serial.println("File Closed");
          }
          buf.txpow = LMIC.radio_txpow;
          send_packet();
          Serial.println("Return after send_packet");
        }

        else {
          if (g_file) {
            g_file.print("}\n");
            g_file.close();
            Serial.println("File Closed");
          }
        }
        if (screen_on){
          // //OLED display update
          


          display.clearDisplay();

          //SCAN SCREEN: Time and date section
          
          // display.setCursor(25, 10);
          // display.print(myGNSS.getMonth());
          // display.print(" / ");
          // display.print(myGNSS.getDay());
          // display.println(" / 2025");

          display.setCursor(10, 10);
          display.print((myGNSS.getHour() - 4)%24);
          display.print(":");
          display.print(myGNSS.getMinute());
          display.print(":");
          display.println(myGNSS.getSecond());

          display.drawLine(0, 30, 128, 30, SH110X_WHITE);

          // SCAN SCREEN: Battery status (top-right corner)
          display.drawRect(110, 2, 16, 8, SH110X_WHITE);  // Battery outline
          display.drawRect(126, 4, 2, 4, SH110X_WHITE);   // Battery terminal



          int batteryFillWidth = voltageToPercent(readBatteryVoltage());

          display.fillRect(112, 4, batteryFillWidth, 4, SH110X_WHITE);
          display.setCursor(100, 10);
          display.print(batteryFillWidth);
          //inputs (x, y, width, height, color)

          display.drawLine(0, 30, 128, 30, SH110X_WHITE);

          //SCAN SCREEN: connection status section
          if (loraConnected) {
            display.drawBitmap(25, 37, signal_icon, 8, 8, SH110X_WHITE);
            display.setCursor(5, 50);
            display.print("Connected");
          } else {
            display.drawBitmap(25, 37, no_signal_icon, 8, 8, SH110X_WHITE);
            display.setCursor(5, 50);
            display.println("No Signal");
          }

          display.drawLine(64, 30, 64, 64, SH110X_WHITE);

          //SCAN SCREEN: Latitude and longitude section
          display.setCursor(80, 40);
          display.print(flat, 4);
          display.println(", ");

          display.setCursor(80, 50);
          display.println(flon, 4);

          display.display();
        }else{
          display.clearDisplay();
          display.display();

        }

      }

      else {
          digitalWrite(LED_BUILTIN, 1);
          delay(100);
          digitalWrite(LED_BUILTIN, 0);
          delay(100);
          digitalWrite(LED_BUILTIN, 1);
          delay(100);
          digitalWrite(LED_BUILTIN, 0);
          delay(100);
          digitalWrite(LED_BUILTIN, 1);
          delay(100);
          digitalWrite(LED_BUILTIN, 0);

        if (screen_on){
          
          // //OLED default display
          // display.setCursor(25, 10);
          // display.print("0");
          // display.print("/");
          // display.println("00/0000");
          display.clearDisplay();

          display.setCursor(20, 13);
          display.print("0");
          display.print(":0");
          display.println(":00");

          display.drawLine(0, 30, 128, 30, SH110X_WHITE);

          // battery
          // SCAN SCREEN: Battery status (top-right corner)
          display.drawRect(110, 2, 16, 8, SH110X_WHITE);  // Battery outline
          display.drawRect(126, 4, 2, 4, SH110X_WHITE);   // Battery terminal

          Serial.print("Voltage: ");
          Serial.println(readBatteryVoltage());
          int batteryFillWidth = voltageToPercent(readBatteryVoltage()) * 15.0 / 100.0;
          display.fillRect(110, 4, batteryFillWidth, 4, SH110X_WHITE);
          display.setCursor(110, 15);
          batteryFillWidth = batteryFillWidth * 100/ 15;
          display.print(batteryFillWidth);


          if (loraConnected) {
            display.drawBitmap(25, 37, signal_icon, 8, 8, SH110X_WHITE);
            display.setCursor(5, 50);
            display.print("Connected");
          } else {
            display.drawBitmap(25, 37, no_signal_icon, 8, 8, SH110X_WHITE);
            display.setCursor(5, 50);
            display.println("No Signal");
          }

          display.drawLine(64, 30, 64, 64, SH110X_WHITE);

          display.display();
        }else{
          display.clearDisplay();
          display.display();

        }
      }
    }
  }
}

// this method is called when the LMIC needs OTAA info.
// return false to indicate "no provisioning", otherwise
// fill in the data and return true.
bool cMyLoRaWAN::GetOtaaProvisioningInfo(
  OtaaProvisioningInfo *pInfo) {
  if (pInfo) {
    memcpy_P(pInfo->AppEUI, APPEUI, 8);
    memcpy_P(pInfo->DevEUI, DEVEUI, 8);
    memcpy_P(pInfo->AppKey, APPKEY, 16);
  }
  return true;
}

void cMyLoRaWAN::NetSaveSessionInfo(
  const SessionInfo &Info,
  const uint8_t *pExtraInfo,
  size_t nExtraInfo) {
  if (!M_FRAM_GOOD) return;
  theFram.saveField(McciCatena::cFramStorage::kNwkSKey, Info.V2.NwkSKey);
  theFram.saveField(McciCatena::cFramStorage::kAppSKey, Info.V2.AppSKey);
  theFram.saveField(McciCatena::cFramStorage::kNetID, Info.V2.NetID);
  theFram.saveField(McciCatena::cFramStorage::kDevAddr, Info.V2.DevAddr);
}

void cMyLoRaWAN::NetSaveSessionState(const SessionState &State) {
  if (!M_FRAM_GOOD) return;
  theFram.saveField(McciCatena::cFramStorage::kLmicSessionState, State);
}

bool cMyLoRaWAN::NetGetSessionState(SessionState &State) {
  if (!M_FRAM_GOOD) return false;
  return theFram.getField(McciCatena::cFramStorage::kLmicSessionState, State);
}

bool cMyLoRaWAN::GetAbpProvisioningInfo(
  AbpProvisioningInfo *pProvisioningInfo) {
  if (!M_FRAM_GOOD) return false;
  bool nd = false;
  if (!pProvisioningInfo) {
    pProvisioningInfo = new AbpProvisioningInfo;
    nd = true;
  }
  SessionState ts;
  if (!theFram.getField(McciCatena::cFramStorage::kLmicSessionState, ts))
    return false;
  if (!theFram.getField(McciCatena::cFramStorage::kAppSKey, pProvisioningInfo->AppSKey) || !theFram.getField(McciCatena::cFramStorage::kNwkSKey, pProvisioningInfo->NwkSKey) || !theFram.getField(McciCatena::cFramStorage::kNetID, pProvisioningInfo->NetID) || !theFram.getField(McciCatena::cFramStorage::kDevAddr, pProvisioningInfo->DevAddr))
    return false;

  pProvisioningInfo->FCntDown = ts.V1.FCntDown;
  pProvisioningInfo->FCntUp = ts.V1.FCntUp;

  if (nd)
    delete pProvisioningInfo;

  Serial.println("Load saved state");
  return true;
}

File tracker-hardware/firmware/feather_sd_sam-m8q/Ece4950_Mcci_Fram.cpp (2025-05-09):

/**************************************************************************/
/*!
    @file     G_MCCI_FRAM_I2C.cpp
    @author   KTOWN (Adafruit Industries)
    @license  BSD (see license.txt)

    Driver for the Adafruit I2C FRAM breakout.

    Adafruit invests time and resources providing this open source code,
    please support Adafruit and open-source hardware by purchasing
    products from Adafruit!

    @section  HISTORY

    v1.0 - First release
    v1.1 - Adapt for FM24CL16B

*/
/**************************************************************************/
//#include <avr/pgmspace.h>
//#include <util/delay.h>
#include <stdlib.h>
#include <math.h>

#include "Ece4950_Mcci_Fram.h"

/*========================================================================*/
/*                            CONSTRUCTORS                                */
/*========================================================================*/

/**************************************************************************/
/*!
    Constructor
*/
/**************************************************************************/
G_MCCI_FRAM_I2C::G_MCCI_FRAM_I2C(void) 
{
  this->m_framInitialized = false;
}

void G_MCCI_FRAM_I2C::prepIO(void) const
	{
	// this->m_pWire->setClock(1000000);
	}

uint8_t G_MCCI_FRAM_I2C::getI2cAddr(uint16_t framAddr) const
	{
	//return this->m_i2c_addr + ((framAddr >> 8) & 0x7);
  return this->m_i2c_addr;
	}

/*========================================================================*/
/*                           PUBLIC FUNCTIONS                             */
/*========================================================================*/

/**************************************************************************/
/*!
    Initializes I2C and configures the chip (call this function before
    doing anything else)
*/
/**************************************************************************/
boolean G_MCCI_FRAM_I2C::begin(uint8_t addr, TwoWire *pWire)
{
  /* scrub and save the address */
  if (addr == 0) // address of 0 is never valid on i2c.
	addr = MB85RC::kDefaultAddress;

  this->m_i2c_addr = addr & ~0x7;
  this->m_pWire = pWire;

  pWire->begin();
  
  /* Make sure we're actually connected ... do a begin/end on each address */
  this->prepIO();
	pWire->beginTransmission(this->m_i2c_addr);
	uint8_t uError = pWire->endTransmission();

	if (uError != 0)
		// device didn't ack
		return false;
	

  /* Everything seems to be properly initialised and connected */
  this->m_framInitialized = true;

  return true;
}

/**************************************************************************/
/*!
    @brief  Writes a byte at the specific FRAM address
    
    @params[in] framAddr
                The address to write to in FRAM memory (reduced modulo 2k)
    @params[in] value
                The 8-bit value to write at framAddr
*/
/**************************************************************************/
void G_MCCI_FRAM_I2C::write8 (uint16_t framAddr, uint8_t value) 
{
  const uint8_t i2c_addr = this->getI2cAddr(framAddr);

  this->prepIO();
  this->m_pWire->beginTransmission(i2c_addr);
  this->m_pWire->write(framAddr >>8);
  this->m_pWire->write(framAddr & 0xFF);
  this->m_pWire->write(value);
  this->m_pWire->endTransmission();
}

/**************************************************************************/
/*!
    @brief  Writes a buffer to the specific FRAM address
    
    @params[in] framAddr
                The address to write to in FRAM memory (reduced mod 2k)
    @params[in] pBuffer
		Address of data in memory.
    @params[in] nBuffer
                number of bytes to write.
*/
/**************************************************************************/
void G_MCCI_FRAM_I2C::write(
	uint16_t framAddr, 
	const uint8_t *pBuffer,
	size_t nBuffer
	)
{
  const uint8_t i2c_addr = this->getI2cAddr(framAddr);

  this->prepIO();

  this->m_pWire->beginTransmission(i2c_addr);
  this->m_pWire->write(framAddr >>8);
  this->m_pWire->write(framAddr & 0xFF);
  this->m_pWire->write(pBuffer, nBuffer);
  this->m_pWire->endTransmission();
}

/**************************************************************************/
/*!
    @brief  Reads an 8 bit value from the specified FRAM address

    @params[in] i2cAddr
                The I2C address of the FRAM memory chip (1010+A2+A1+A0)
    @params[in] framAddr
                The 16-bit address to read from in FRAM memory

    @returns    The 8-bit value retrieved at framAddr
*/
/**************************************************************************/
uint8_t G_MCCI_FRAM_I2C::read8 (uint16_t framAddr)
{
  const uint8_t i2c_addr = this->getI2cAddr(framAddr);

  this->prepIO();
  this->m_pWire->beginTransmission(i2c_addr);
  this->m_pWire->write(framAddr >>8);
  this->m_pWire->write(framAddr & 0xFF);
  this->m_pWire->endTransmission();

  this->m_pWire->requestFrom(i2c_addr, (uint8_t)1);
  while (! this->m_pWire->available())
	/* loop */;

  return this->m_pWire->read();
}

/**************************************************************************/
/*!
    @brief  Reads a buffer from the specified FRAM address

    @params[in] framAddr
                The 16-bit address to read from in FRAM memory
    @params[in] pBuffer
		The base address of the buffer to be filled
    @params[in] nBuffer
		Number of bytes to read.

    @returns    The 8-bit value retrieved at framAddr
*/
/**************************************************************************/
uint8_t G_MCCI_FRAM_I2C::read (uint16_t framAddr, uint8_t *pBuffer, size_t nBuffer)
{
  uint8_t const i2c_addr = this->getI2cAddr(framAddr);

  this->prepIO();
  this->m_pWire->beginTransmission(i2c_addr);
  this->m_pWire->write(framAddr >>8);
  this->m_pWire->write(framAddr & 0xFF);
  this->m_pWire->endTransmission();

  // we can only read 255 bytes at a time.
  if (nBuffer > 0xFF)
	nBuffer = 0xFF;

  this->m_pWire->requestFrom(i2c_addr, (uint8_t) nBuffer);
  uint8_t const save_nBuffer = nBuffer;

  while (this->m_pWire->available() && nBuffer > 0)
	{
	*pBuffer++ = this->m_pWire->read();
	--nBuffer;
	}

  return save_nBuffer - nBuffer;
}
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

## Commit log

2025-05-09 reorg, add hardware/firmware
    [Back_new.stl, Back_new.stp, Bottom Case.stl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]
2025-05-09 reorg CAD, add purple board
    [Back_new.stl, Back_new.stp, Bottom Case.stl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]
